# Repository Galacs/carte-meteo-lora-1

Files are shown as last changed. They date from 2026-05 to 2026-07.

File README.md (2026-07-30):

# Carte Meteo Lora 1

Solar and battery powered LoRa weather station

## IC List

- STM32L431CCT6 (Low power MCU)
- HT7150 (+3V3 LDO)
- SX1262TR8 (SX1262 LoRa module)
- WS2812B (Addressable RGB LED)
- MS5607 (Pressure sensor)
- GXHT30 (Humidity and temperature sensor)
- HTU21D (Humidity and temperature sensor)
- BQ25798 (1s battery charger with MPPT)
- TPS6282 (SMPS)

## Top preview



## Preview 3d render



## Pictures

## Pin definitions

```c
#define LORA_RST_PIN PB0
#define LORA_DIO1_PIN PB1
#define LORA_BUSY_PIN PB11
#define LORA_DIO3_PIN PB10
#define LORA_CS_PIN PA4
#define LORA_SCK_PIN PA5
#define LORA_MISO_PIN PA6
#define LORA_MOSI PA7

#define BTN_PIN PB12
#define STATUS_PIN PB13

#define SCL_PIN PB6
#define SDA_PIN PB7
#define CE_PIN PA11
#define INT_PIN PA12
#define QON_PIN PA10

#define RGB_PIN PC13

#define RAIN_PIN PB4
#define W_DIR_PIN PA1
#define WIND_PIN PA0
```

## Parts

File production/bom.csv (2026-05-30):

Designator | Footprint | Quantity | Value | LCSC Part #
C1, C2, C23, C24, C28, C29, C3, C30, C31, C32, C33, C34, C35, C36 | 0805 | 14 | 10u | C440198
C10, C11, C15, C16, C18, C19, C20, C21, C6, C7, C9 | 0402 | 11 | 0u1 | C307331
C12, C13, C8 | 0402 | 3 | 1u | C52923
C14 | 0402 | 1 | 10n | C15195
C17, C39, C40 | 0402 | 3 | 10u | C15525
C22 | 0603 | 1 | 4u7 | C19666
C25, C26 | 0603 | 2 | 47n | C1622
C27 | 0402 | 1 | 1n | C1523
C37 | 0603 | 1 | 10u | C19702
C38 | 0402 | 1 | 100p | C1546
C4, C5 | 0603 | 2 | 20p | C1648
D1, D10, D11, D2, D3, D4, D5, D8, D9 | Diode_DFN1006 | 9 | H5VU10U | C22395519
D12 | 0805 | 1 | GREEN | C2297
D6 | LED_WS2812B_PLCC4_5.0x5.0mm_P3.2mm | 1 | WS2812B | C2874885
D7 | 0805 | 1 | YELLOW | C2296
FB1 | 0805 | 1 | 600Ω@100M | C81034
J2, J3 | RJ25_Wayconn_MJEA-660X1_Horizontal | 2 | Conn_01x04 | C189750
J4 | SMA_BAT_Wireless_BWSMA-KWE-Z001 | 1 | Conn_Coaxial | C496551
J5 | USB_C_Receptacle_HRO_TYPE-C-31-M-12 | 1 | USB_C_Receptacle_USB2.0_14P | C393939
J6 | JST_XH_B2B-XH-A_1x02_P2.50mm_Vertical | 1 | Solar_Cell | C158012
J7 | JST_XH_B2B-XH-A_1x02_P2.50mm_Vertical | 1 | Conn_01x02 | C158012
J8 | AMASS_XT30PW-M_1x02_P2.50mm_Horizontal | 1 | Battery_Cell | C431092
JP1, JP2, JP3, JP4, JP5 | PinHeader_1x02_P2.54mm_Vertical | 5 | Jumper_2_Small_Bridged
L1 | L_Changjiang_FXL0420 | 1 | 1u | C167203
L2 | TDK_TFM201610ALC | 1 | 0u47 | C2045043
Q1, Q2 | SOIC-8_3.9x4.9mm_P1.27mm | 2 | AO4882 | C3040598
R1, R11, R12, R15, R3, R4, R6, R8 | 0402 | 8 | 10k | C25744
R10, R16, R5, R9 | 0402 | 4 | 5k1 | C25905
R13, R20 | 0402 | 2 | 100k | C25741
R14 | 0402 | 1 | 52k3 | C26982
R17 | 0603 | 1 | 3k | C4211
R18 | 0402 | 1 | 100 | C25076
R19 | 0603 | 1 | 430k | C25969
R2 | 0603 | 1 | 560 | C23204
R7 | 0603 | 1 | 470k | C23178
SW1, SW2, SW3 | SW_SPST_TS-1088-xR020 | 3 | SW_Push | C720477
TP4 | TestPoint_Pad_D2.0mm | 1 | TestPoint
U1 | SOT-89-3 | 1 | HT7150-1 | C347184
U2 | LQFP-48_7x7mm_P0.5mm | 1 | STM32L431CCTx | C486681
U3 | LGA-8_3x5mm_P1.25mm | 1 | MS5607-02BA | C97627
U4 | Sensirion_DFN-8-1EP_2.5x2.5mm_P0.5mm_EP1.1x1.7mm | 1 | GXHT30 | C2913569
U5 | Silicontra_SX1262ZTR8 | 1 | SX1262TR8-GC | C42381682
U6 | Texas_PWSON-N6 | 1 | HTU21 | C83479
U7 | Texas_RQM0029A_VQFN-29_4x4mm_P0.4mm | 1 | BQ25798 | C2876593
U8 | Texas_VSON-6_1.5x1.5mm_P0.5mm_DMQ0006A | 1 | TPS6282x | C2650334
Y1 | Crystal_SMD_5032-2Pin_5.0x3.2mm | 1 | 8M | C115962

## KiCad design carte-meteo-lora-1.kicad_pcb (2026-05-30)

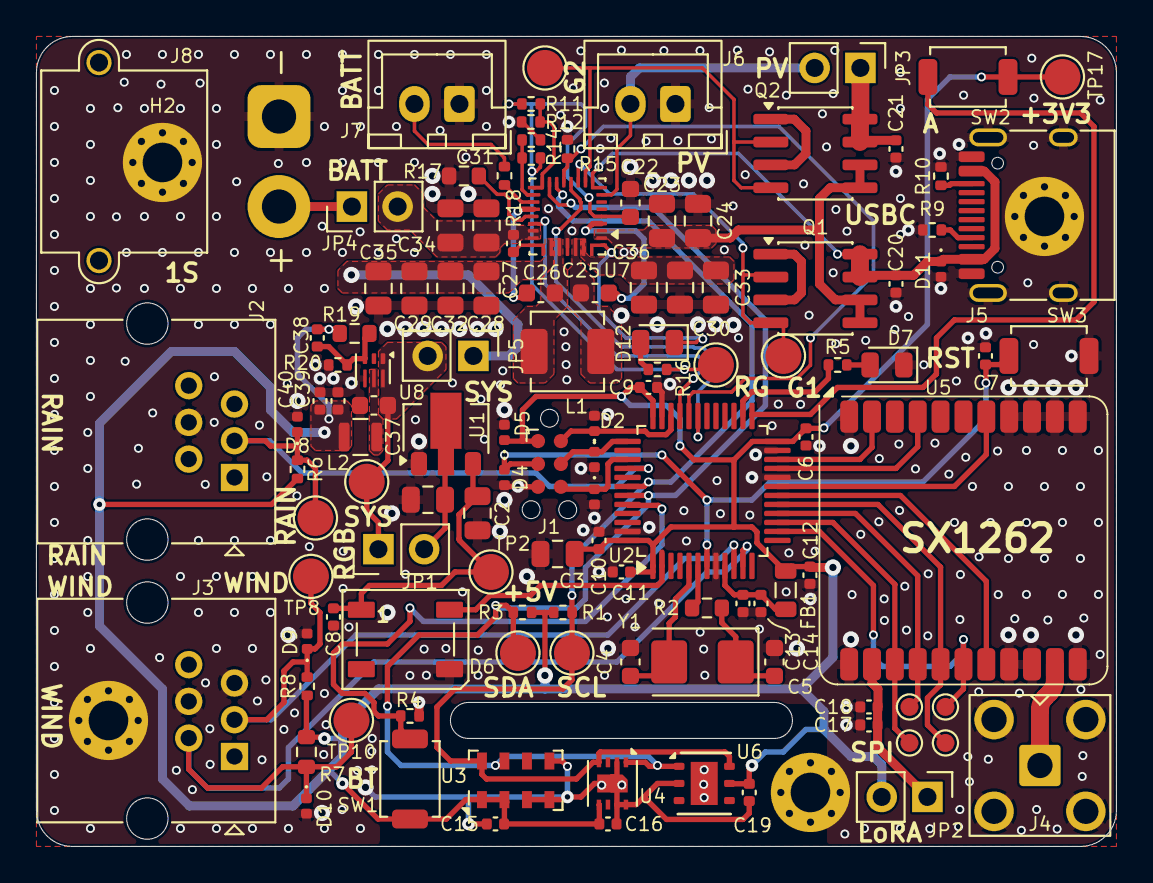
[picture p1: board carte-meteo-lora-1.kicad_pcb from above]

Board: 2 copper layers, 60.0 x 45.0 mm, 121 parts (0 on the bottom side), 60 nets.

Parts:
C1, C2, C3, C23, C24, C28, C29, C30, C31, C32, C33, C34, C35, C36: 10u; C_0805_2012Metric
C4, C5: 20p; C_0603_1608Metric
C6, C7, C9, C10, C11, C15, C16, C18, C19, C20, C21: 0u1; C_0402_1005Metric
C8, C12, C13: 1u; C_0402_1005Metric
C14: 10n; C_0402_1005Metric
C17, C39, C40: 10u; C_0402_1005Metric
C22: 4u7; C_0603_1608Metric
C25, C26: 47n; C_0603_1608Metric
C27: 1n; C_0402_1005Metric
C37: 10u; C_0603_1608Metric
C38: 100p; C_0402_1005Metric
D1, D2, D3, D4, D5, D8, D9, D10, D11: H5VU10U; Diode_DFN1006
D6: WS2812B; LED_WS2812B_PLCC4_5.0x5.0mm_P3.2mm
D7: YELLOW; LED_0805_2012Metric
D12: GREEN; LED_0805_2012Metric
FB1: 600Ω@100M; L_0805_2012Metric
H1, H2, H3, H4: MountingHole_Pad; MountingHole_2.2mm_M2_Pad_Via
J1: TC2030; Tag-Connect_TC2030-IDC-NL_2x03_P1.27mm_Vertical
J2, J3: Conn_01x04; RJ25_Wayconn_MJEA-660X1_Horizontal
J4: Conn_Coaxial; SMA_BAT_Wireless_BWSMA-KWE-Z001
J5: USB_C_Receptacle_USB2.0_14P; USB_C_Receptacle_HRO_TYPE-C-31-M-12
J6: Solar_Cell; JST_XH_B2B-XH-A_1x02_P2.50mm_Vertical
J7: Conn_01x02; JST_XH_B2B-XH-A_1x02_P2.50mm_Vertical
J8: Battery_Cell; AMASS_XT30PW-M_1x02_P2.50mm_Horizontal
JP1, JP2, JP3, JP4, JP5: Jumper_2_Small_Bridged; PinHeader_1x02_P2.54mm_Vertical
L1: 1u; L_Changjiang_FXL0420
L2: 0u47; TDK_TFM201610ALC
Q1, Q2: AO4882; SOIC-8_3.9x4.9mm_P1.27mm
R1, R3, R4, R6, R8, R11, R12, R15: 10k; R_0402_1005Metric
R2: 560; R_0603_1608Metric
R5, R9, R10, R16: 5k1; R_0402_1005Metric
R7: 470k; R_0603_1608Metric
R13, R20: 100k; R_0402_1005Metric
R14: 52k3; R_0402_1005Metric
R17: 3k; R_0603_1608Metric
R18: 100; R_0402_1005Metric
R19: 430k; R_0603_1608Metric
SW1, SW2, SW3: SW_Push; SW_SPST_TS-1088-xR020
TP1, TP2, TP3, TP4, TP6, TP8, TP10, TP13, TP14, TP15, TP17: TestPoint; TestPoint_Pad_D2.0mm
TP7, TP9, TP11, TP12: TestPoint; TestPoint_Pad_D1.0mm
U1: HT7150-1; SOT-89-3
U2: STM32L431CCTx; LQFP-48_7x7mm_P0.5mm
U3: MS5607-02BA; LGA-8_3x5mm_P1.25mm
U4: GXHT30; Sensirion_DFN-8-1EP_2.5x2.5mm_P0.5mm_EP1.1x1.7mm
U5: SX1262TR8-GC; Silicontra_SX1262ZTR8
U6: HTU21; Texas_PWSON-N6
U7: BQ25798; Texas_RQM0029A_VQFN-29_4x4mm_P0.4mm
U8: TPS6282x; Texas_VSON-6_1.5x1.5mm_P0.5mm_DMQ0006A
Y1: 8M; Crystal_SMD_5032-2Pin_5.0x3.2mm

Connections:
+3V3: C3.1, C6.1, C9.1, C10.1, C11.1, C12.1, C15.2, C16.2, C17.1, C18.2, C19.2, C38.1, C39.1, C40.1, D5.1 (K), FB1.2, J1.1 (VCC), JP2.1 (A), JP2.2 (B), L2.2, R1.2, R3.1, R6.2, R7.1, R8.1, R19.1, SW1.1, SW2.1, TP17.1 (1_1), U2.1 (VBAT), U2.24 (VDD), U2.36 (VDD), U2.48 (VDD), U3.1 (VDD), U3.2 (PS), U4.5 (VDD), U5.13 (VCC), U6.5 (VCC)
+5V: C2.1, C8.1, D6.1 (VDD), TP2.1 (1_1), U1.3 (VOUT)
+REGN: C22.1, R11.1, R13.1, R16.2, TP15.1 (1_1), U7.5 (REGN)
+SYS: C1.1, C28.1, C29.1, C32.1, C35.1, C37.1, JP1.1 (A), JP1.2 (B), JP5.1 (A), JP5.2 (B), TP1.1 (1_1), U1.2 (VIN), U7.25 (SYS), U8.1 (EN), U8.6 (VIN)
+Vbus: C20.1, D11.1 (K), J5.A4 (VBUS), J5.A9 (VBUS), J5.B4 (VBUS), J5.B9 (VBUS), Q1.7 (D1), Q1.8 (D1), U7.9 (VAC1)
/BOOT: R4.2, SW1.2, U2.44 (PH3)
/BTN1: SW2.2, U2.25 (PB12)
/BUSY: U2.22 (PB11), U5.10 (BUSY)
/CS: TP9.1 (1_1), U2.14 (SPI1_NSS), U5.17 (CS)
/DIO1: U2.19 (PB1), U5.5 (DIO1)
/DIO3: U2.21 (PB10), U5.8 (DIO3)
/MISO: TP11.1 (1_1), U2.16 (SPI1_MISO), U5.15 (MISO)
/MOSI: TP12.1 (1_1), U2.17 (SPI1_MOSI), U5.16 (MOSI)
/NRST: C7.2, D4.1 (K), J1.3 (~RESET), SW3.2, U2.7 (NRST)
/Power/~CE: R15.2, U2.32 (PA11), U7.13 (~CE)
/Power/~INT: U2.33 (PA12), U7.21 (~INT)
/Power/~QON: U2.31 (PA10), U7.12 (~QON)
/RAIN: D8.1 (K), J2.3, R6.1, TP6.1 (1_1), U2.40 (PB4)
/RF_LR: J4.1 (In), U5.21 (ANT)
/RGB1: D6.4 (DIN), U2.2 (PC13)
/RST: U2.18 (PB0), U5.18 (RST)
/SCK: TP7.1 (1_1), U2.15 (SPI1_SCK), U5.14 (SCK)
/SCL: R1.1, TP3.1 (1_1), U2.42 (I2C1_SCL), U3.8 (SCLK), U4.4 (SCL), U6.6 (SCL), U7.14 (SCL)
/SDA: R3.2, TP4.1 (1_1), U2.43 (I2C1_SDA), U3.7 (SDI/SDA), U4.1 (SDA), U6.1 (SDA), U7.15 (SDA)
/SWCLK: D3.1 (K), J1.4 (SWCLK), U2.37 (SWCLK)
/SWDIO: D2.1 (K), J1.2 (SWDIO), U2.34 (IR_OUT)
/SWO: D1.1 (K), J1.6 (SWO), U2.39 (SWO)
/WIND: D9.1 (K), J3.3, R8.2, TP8.1 (1_1), U2.10 (PA0)
/W_DIR: D10.1 (K), J3.2, R7.2, TP10.1 (1_1), U2.11 (ADC1_IN6)
/XTAL_I: C4.1, U2.5 (RCC_OSC_IN), Y1.2
/XTAL_O: R2.2, U2.6 (RCC_OSC_OUT)
/XTAL_RO: C5.1, R2.1, Y1.1
GND: C1.2, C2.2, C3.2, C4.2, C5.2, C6.2, C7.1, C8.2, C9.2, C10.2, C11.2, C12.2, C13.2, C14.2, C15.1, C16.1, C17.2, C18.1, C19.1, C20.2, C21.2, C22.2, C23.2, C24.2, C28.2, C29.2, C30.2, C31.2, C32.2, C33.2, C34.2, C35.2, C36.2, C37.2, C39.2, C40.2, D1.2 (A), D2.2 (A), D3.2 (A), D4.2 (A), D5.2 (A), D6.3 (VSS), D7.1 (K), D8.2 (A), D9.2 (A), D10.2 (A), D11.2 (A), H1.1 (1_1), H2.1 (1_1), H3.1 (1_1), H4.1 (1_1), J1.5 (GND), J2.4, J3.4, J3.5, J4.2 (Ext), J5.A1 (GND), J5.A12 (GND), J5.B1 (GND), J5.B12 (GND), J5.SH (SHIELD), J6.1 (+), J7.1, J8.1 (+), R4.1, R9.1, R10.1, R12.1, R14.1, R15.1, R17.2, R20.2, SW3.1, U1.1 (GND), U2.8 (VSSA), U2.20 (PB2), U2.23 (VSS), U2.35 (VSS), U2.47 (VSS), U3.3 (GND), U3.4 (CSB), U3.5 (CSB), U4.2 (ADDR), U4.7 (R), U4.8 (VSS), U4.9 (VSS), U5.1 (GND), U5.2 (GND), U5.3 (GND), U5.4 (GND), U5.11 (GND), U5.12 (GND), U5.19 (GND), U5.20 (GND), U5.22 (GND), U6.2 (GND), U7.27 (GND), U8.4 (GND)
unnamed: C23.1, C24.1, Q1.5 (D2), Q1.6 (D2), Q2.5 (D2), Q2.6 (D2), U7.2 (VBUS), U7.3 (VBUS)
unnamed: D7.2 (A), R5.2
unnamed: D12.2 (A), R16.1
unnamed: D12.1 (K), U7.1 (STAT)
unnamed: J5.A5 (CC1), R9.2
unnamed: J5.B5 (CC2), R10.2
unnamed: C21.1, J6.2 (-), JP3.1 (A), JP3.2 (B), Q2.7 (D1), Q2.8 (D1), U7.8 (VAC2)
unnamed: J7.2, R18.1
unnamed: C27.2, C31.1, C34.1, J8.2 (-), JP4.1 (A), JP4.2 (B), U7.22 (BAT), U7.23 (BAT)
unnamed: Q1.2 (G1), Q1.4 (G2), TP13.1 (1_1), U7.11 (ACDRV1)
unnamed: Q1.1 (S1), Q1.3 (S2)
unnamed: Q2.2 (G1), Q2.4 (G2), TP14.1 (1_1), U7.10 (ACDRV2)
unnamed: Q2.1 (S1), Q2.3 (S2)
unnamed: R5.1, U2.26 (PB13)
unnamed: C13.1, C14.1, FB1.1, U2.9 (VDDA)
unnamed: R18.2, U7.18 (BATP)
unnamed: C25.1, U7.4 (BTST1)
unnamed: C26.1, U7.19 (BTST2)
unnamed: R13.2, R14.2, U7.17 (ILIM_HIZ)
unnamed: C30.1, C33.1, C36.1, U7.29 (PMID)
unnamed: R17.1, U7.20 (PROG)
unnamed: C27.1, U7.24 (SDRV)
unnamed: C25.2, L1.1, U7.28 (SW1)
unnamed: C26.2, L1.2, U7.26 (SW2)
unnamed: R11.2, R12.2, U7.16 (TS)
unnamed: C38.2, R19.2, R20.1, U8.3 (FB)
unnamed: L2.1, U8.5 (SW)

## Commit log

2026-05-19 remove TMP117 temp sensor
    [carte-meteo-lora-1.kicad_sch]
2026-05-19 schem: add MS5607 Pressure sensor
    [carte-meteo-lora-1.kicad_sch]
2026-05-20 schem: remove old gpios
    [carte-meteo-lora-1.kicad_sch]
2026-05-20 schem: add esp32-c5 with decoupling caps
    [carte-meteo-lora-1.kicad_sch]
2026-05-20 schem: replace esp32-s3 with esp32-c5
    [carte-meteo-lora-1.kicad_sch]
2026-05-20 schem: add GXHT30 humidity and temperature sensor
    [carte-meteo-lora-1.kicad_sch]
2026-05-20 schem: add HTU21 humidity and temperature
    [carte-meteo-lora-1.kicad_sch]
2026-05-20 schem: add wind and rain connectors
    [carte-meteo-lora-1.kicad_sch]
2026-05-20 schem: add SX1262 based lora module
    [carte-meteo-lora-1.kicad_sch]
2026-05-21 schem: add ordering info to BOM
    [carte-meteo-lora-1.kicad_sch]
2026-05-21 schem: fix BOM
    [carte-meteo-lora-1.kicad_sch]
2026-05-24 schem: add esp rf matching networks
    [carte-meteo-lora-1.kicad_sch, radio.kicad_sch]
2026-05-24 schem: reorganize
    [carte-meteo-lora-1.kicad_sch, power.kicad_sch]
2026-05-24 schem: add TPS62933 5V SMPS
    [power.kicad_sch]
2026-05-24 schem: rf fix switchable connectors orientation
    [carte-meteo-lora-1.kicad_sch, radio.kicad_sch]
2026-05-24 schem: fix VDD_SPI cap
    [carte-meteo-lora-1.kicad_sch, power.kicad_sch]
2026-05-24 schem: improve rain and wind connectors
    [carte-meteo-lora-1.kicad_sch]
2026-05-24 schem: add rain/wind schmitt trigger
    [carte-meteo-lora-1.kicad_sch, power.kicad_sch, radio.kicad_sch]
2026-05-25 schem: remove 3s BMS
    [power.kicad_sch]
2026-05-25 schem: add BQ25798 MPPT/Charger/Protection/Boost
    [power.kicad_sch]
2026-05-25 schem: add TPS6282 3.3v SMPS
    [power.kicad_sch]
2026-05-25 schem: remove esp32
    [carte-meteo-lora-1.kicad_sch, power.kicad_sch, radio.kicad_sch]
2026-05-25 schem: add STM32F103C8Tx
    [carte-meteo-lora-1.kicad_sch, radio.kicad_sch]
2026-05-25 schem: add usbc pwer connector
    [power.kicad_sch]
2026-05-25 schem: remove oled display
    [carte-meteo-lora-1.kicad_sch]
2026-05-25 schem: add HT7150-1 5V LDO for rgb led
    [carte-meteo-lora-1.kicad_sch]
2026-05-25 schem: connect gpios
    [carte-meteo-lora-1.kicad_sch, power.kicad_sch]
2026-05-26 schem: change mcu to stm32l4
    [carte-meteo-lora-1.kicad_sch, power.kicad_sch]
2026-05-26 schem: connect gpios to mcu
    [carte-meteo-lora-1.kicad_sch]
2026-05-26 schem: add current measure jumpers
    [carte-meteo-lora-1.kicad_sch, power.kicad_sch]
2026-05-26 schem: add no connects
    [carte-meteo-lora-1.kicad_sch, power.kicad_sch]
2026-05-26 schem: add test points
    [carte-meteo-lora-1.kicad_sch, power.kicad_sch]
2026-05-26 schem: run and fix ERC
    [power.kicad_sch]
2026-05-26 schem: add net classes
    [carte-meteo-lora-1.kicad_sch]
2026-05-26 schem: assign footprints
    [carte-meteo-lora-1.kicad_sch, power.kicad_sch]
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2026-05-26 pcb: import jlc 2 layer stackup
    [carte-meteo-lora-1.kicad_pcb]
2026-05-26 pcb: add missing 3d models
    [carte-meteo-lora-1.kicad_pcb, power.kicad_sch]
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2026-05-29 schem: add title to other sheet
    [power.kicad_sch]
2026-05-29 pcb: add missing lora 3d model
    [carte-meteo-lora-1.kicad_pcb]
2026-05-29 pcb: add usb layout
    [carte-meteo-lora-1.kicad_pcb]
2026-05-29 pcb: add solar charger layout
    [carte-meteo-lora-1.kicad_pcb, power.kicad_sch]
2026-05-29 pcb: add rgb led routing
    [carte-meteo-lora-1.kicad_pcb, carte-meteo-lora-1.kicad_sch]
2026-05-29 pcb: add smps routing
    [carte-meteo-lora-1.kicad_pcb]
2026-05-29 pcb: add wind/rain connectors layout
    [carte-meteo-lora-1.kicad_pcb]
2026-05-29 pcb: add sensors layout
    [carte-meteo-lora-1.kicad_pcb]
2026-05-29 pcb: add lora layout
    [carte-meteo-lora-1.kicad_pcb]
2026-05-29 pcb: add stm32 layout
    [carte-meteo-lora-1.kicad_pcb, carte-meteo-lora-1.kicad_sch]
2026-05-29 pcb: add board outline and final placement
    [carte-meteo-lora-1.kicad_pcb]
2026-05-29 schem: add mounting holes
    [carte-meteo-lora-1.kicad_pcb, carte-meteo-lora-1.kicad_sch]
2026-05-29 pcb: add gnd planes
    [carte-meteo-lora-1.kicad_pcb]
2026-05-29 pcb: add gnd vias
    [carte-meteo-lora-1.kicad_pcb]
2026-05-29 pcb: add grid/place origin
    [carte-meteo-lora-1.kicad_pcb]
2026-05-29 pcb: reorganize programmable gpios
    [carte-meteo-lora-1.kicad_pcb, carte-meteo-lora-1.kicad_sch]
2026-05-29 pcb: add rf routing
    [carte-meteo-lora-1.kicad_pcb]
2026-05-29 pcb: add xtal routing
    [carte-meteo-lora-1.kicad_pcb]
2026-05-29 pcb: add swd routing
    [carte-meteo-lora-1.kicad_pcb]
2026-05-29 pcb: add i2c routing
    [carte-meteo-lora-1.kicad_pcb]
2026-05-29 pcb: add solar charger routing
    [carte-meteo-lora-1.kicad_pcb]
2026-05-29 pcb: add lora spi routing
    [carte-meteo-lora-1.kicad_pcb]
2026-05-29 pcb: add rain/wind connectors routing
    [carte-meteo-lora-1.kicad_pcb, carte-meteo-lora-1.kicad_sch]
2026-05-29 pcb: add smps and +5v pwr routing
    [carte-meteo-lora-1.kicad_pcb]
2026-05-29 pcb: add lora gpio routing
    [carte-meteo-lora-1.kicad_pcb]
2026-05-29 pcb: add boot/rst routing
    [carte-meteo-lora-1.kicad_pcb, carte-meteo-lora-1.kicad_sch]
2026-05-29 pcb: connect charger to mcu
    [carte-meteo-lora-1.kicad_pcb]
2026-05-29 pcb: add +3v3 pwr routing
    [carte-meteo-lora-1.kicad_pcb, carte-meteo-lora-1.kicad_sch]
2026-05-30 pcb: add missing connections
    [carte-meteo-lora-1.kicad_pcb]
2026-05-30 pcb: add stitching vias
    [carte-meteo-lora-1.kicad_pcb]
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2026-05-30 pcb: add temp sensors thermal pads
    [carte-meteo-lora-1.kicad_pcb]
2026-05-30 pcb(silk): add user txt
    [carte-meteo-lora-1.kicad_pcb]
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
